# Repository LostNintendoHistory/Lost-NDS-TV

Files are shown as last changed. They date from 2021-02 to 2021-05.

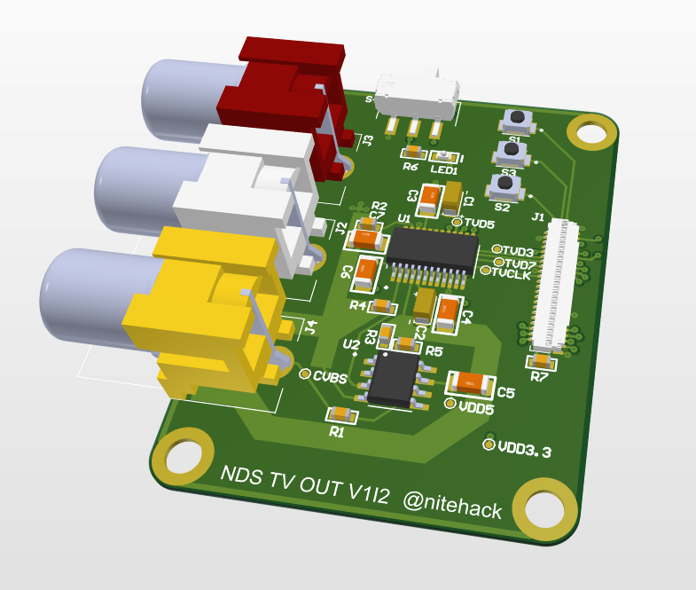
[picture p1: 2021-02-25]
pcb/media/3d_pcb_nds_tv_out_V1I2.PNG

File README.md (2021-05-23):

# Lost-NDS-TV

## Introduction

On December 2020, we discovered that the Nintendo DS Lite's SoC (System on Chip) had a hidden feature: a leftover TV(Television) composite video output signal. This project contains our hardware designs and software code to restore this hidden feature and make it usable again. More details [here](https://lostnintendohistory.github.io/DS-TV-OUT)

## Contents

 * Schematics & design & BOM
   * Can be found in this respository under /pcb
 * Production Files
   * Gerber files are available in the [releases page](https://github.com/LostNintendoHistory/Lost-NDS-TV/releases)
 * Documentation
   * Some base explaination of how the system works, how the PCB and software act altogether, etc. can be found [here](https://lostnintendohistory.github.io/DS-TV-OUT) after the Installation section
 * Tutorials
   * For a quick installation/usage tutorial, [click here](https://lostnintendohistory.github.io/DS-TV-OUT)
   * Video Tutorial coming later this month

## Video Tutorial for Installation

NDS TV OUT Installation Tutorial by radioactivepeter (https://www.youtube.com/watch?v=lBJaaE3PBwQ)

## Video analysis + installation tutorial by MachoNacho

SECRET Nintendo DS Feature Discovered! How to Enable Video-Output on the DS Lite (https://www.youtube.com/watch?v=F4n9oYBFiMI&t=1s&ab_channel=MachoNachoProductions)

## Acknowledgements 

This project wouldn't be possible without the contributions of Gericom, Nitehack and pedro-javierf.

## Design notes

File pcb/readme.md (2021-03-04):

# PCB Design Files
You have to have good soldering skills to mount the PCB with the proper equipment. A soldering station and good quality tin is recommended 

**Warning: We are not responsible for possible damage both hardware and software.
Do it under your responsibility **

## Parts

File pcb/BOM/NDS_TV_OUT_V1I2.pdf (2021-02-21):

Comment | Description | Designator | Footprint | LibRef | Quantity | Manufacturer Part Number
MAX5184BEEG+ | DAC 1-CH Current Steering 10-bit 24-Pin QSOP | U1 | SOP63P602 X175-24N | MAX5184BEEG+ | 1 | MAX5184BEEG+
MAX4414ESA+ | IC OPAMP VFB 400MHZ RRO 8SOIC | U2 | SOIC127P60 0X175-8N | MAX4414ESA+ | 1 | MAX4414ESA+
KLPX-0848A-2-Y | Conn RCA F 2 POS 4.5mm Solder RA Thru-Hole 2 Terminal 1 Port | J4 | KLPX0848A2 Y | KLPX-0848A-2-Y | 1 | KLPX-0848A-2-Y
KLPX-0848A-2-W | Conn RCA F 2 POS 4.5mm Solder RA Thru-Hole 2 Terminal 1 Port | J2 | KLPX0848A2 W | KLPX-0848A-2-W | 1 | KLPX-0848A-2-W
KLPX-0848A-2-R | Conn RCA F 2 POS 4.5mm Solder RA Thru-Hole 2 Terminal 1 Port | J3 | KLPX0848A2 R | KLPX-0848A-2-R | 1 | KLPX-0848A-2-R
JS102011SAQN | Slide Switch, JS Series, SPDT, Right Angle, SMD, 100 mA ;RoHS Compliant: Yes | S4 | SW_JS10201 1SAQN | JS102011SAQN | 1 | JS102011SAQN
DNP | | R2, R4 | R0603 | R0603 | 2
B3U-1000P | SWITCH TACTILE SPST-NO 0.05A 12V | S1, S2, S3 | SW_B3U-1000P | B3U-1000P | 3 | B3U-1000P
APTD1608LZGCK | LED GREEN CLEAR 0603 SMD | LED1 | RESC0603X5 5N | APTD1608LZGCK | 1 | APTD1608LZGCK
430R | Res, 430R, 0.1%, 0.1W, 0603, Thin | R3 | R0603 | MCWF06R4300B TL | 1 | MCWF06R4300BTL
320R | Film High Precision-High Stability Chip Resistor Thin Film 0603 320Ohm 0.5% Paper T/R | R6 | R0603 | RT0603DRE07320 RL | 1 | RT0603DRE07320RL
75R | VISHAY -CRCW060375R 0FKEA - RES, 75R, 1%, 0.1W, 0603, THICK FILM | R1 | R0603 | CRCW060375R0F KEA | 1 | CRCW060375R0FKEA
10uF | CAPACITOR, CASE A, 10UF, 10V; Product Range:KEMET -T491 Series; Capacitance:1 0µF; Capacitance Tolerance:± 10%; Voltage Rating:10V; Capacitor Case Style:1206 [3216 Metric]; Manufacturer Size Code:A; Operating Temperature Max:125°C; ;RoHS Compliant: Yes | C1, C2 | C1206T | T491A106K010AT | 2 | T491A106K010AT
4-2328724-5 | FPC Connector; 0.3mm pitch front flip FPC; 45pos | J1 | 423287245 | 4-2328724-5 | 1 | 4-2328724-5
1K | ROHM -ESR03EZPF100 1 - SMD Chip Resistor, Anti-Surge, 0603 [1608 Metric], 1 kohm, ESR Series, 150 V, Thick Film, 250 mW | R5, R7 | R0603 | ESR03EZPF1001 | 2 | ESR03EZPF1001
0.1uF | MURATA -GRM319R71H 104KA01D -COND, CERÁ MULT, X7R, 100NF, 50V, 1206 | C3, C4, C5, C6, C7 | C1206 | GRM319R71H10 4KA01D | 5 | GRM319R71H104KA01D
Ribbon Cable FPC 0,3mm pitch 45 pin | | | | | 1 | https://es.aliexpress.com/it
em/4000499971802.html?s
pm=a2g0s.9042311.0.0.415
d63c0FOSqsK (https://es.aliexpress.com/item/4000499971802.html?spm=a2g0s.9042311.0.0.415d63c0FOSqsK)

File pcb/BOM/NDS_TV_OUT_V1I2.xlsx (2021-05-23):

Comment | Description | Designator | Footprint | LibRef | Quantity | Manufacturer Part Number
MAX5184BEEG+ | DAC 1-CH Current Steering 10-bit 24-Pin QSOP | U1 | SOP63P602X175-24N | MAX5184BEEG+ | 1 | MAX5184BEEG+
MAX4414ESA+ | IC OPAMP VFB 400MHZ RRO 8SOIC | U2 | SOIC127P600X175-8N | MAX4414ESA+ | 1 | MAX4414ESA+
KLPX-0848A-2-Y | Conn RCA F 2 POS 4.5mm Solder RA Thru-Hole 2 Terminal 1 Port | J4 | KLPX0848A2Y | KLPX-0848A-2-Y | 1 | KLPX-0848A-2-Y
KLPX-0848A-2-W | Conn RCA F 2 POS 4.5mm Solder RA Thru-Hole 2 Terminal 1 Port | J2 | KLPX0848A2W | KLPX-0848A-2-W | 1 | KLPX-0848A-2-W
KLPX-0848A-2-R | Conn RCA F 2 POS 4.5mm Solder RA Thru-Hole 2 Terminal 1 Port | J3 | KLPX0848A2R | KLPX-0848A-2-R | 1 | KLPX-0848A-2-R
JS102011SAQN | Slide Switch, JS Series, SPDT, Right Angle, SMD, 100 mA ;RoHS Compliant: Yes | S4 | SW_JS102011SAQN | JS102011SAQN | 1 | JS102011SAQN
DNP |  | R2, R4 | R0603 | R0603 | 2
B3U-1000P | SWITCH TACTILE SPST-NO 0.05A 12V | S1, S2, S3 | SW_B3U-1000P | B3U-1000P | 3 | B3U-1000P
APTD1608LZGCK | LED GREEN CLEAR 0603 SMD | LED1 | RESC0603X55N | APTD1608LZGCK | 1 | APTD1608LZGCK
430R | Res, 430R, 0.1%, 0.1W, 0603, Thin Film | R3 | R0603 | MCWF06R4300BTL | 1 | MCWF06R4300BTL
320R | High Precision-High Stability Chip Resistor Thin Film 0603 320Ohm 0.5% Paper T/R | R6 | R0603 | RT0603DRE07320RL | 1 | RT0603DRE07320RL
75R | VISHAY - CRCW060375R0FKEA - RES, 75R, 1%, 0.1W, 0603, THICK FILM | R1 | R0603 | RC0603FR-0775RL | 1 | RC0603FR-0775RL
10uF | CAPACITOR, CASE A, 10UF, 10V; Product Range:KEMET - T491 Series; Capacitance:10µF; Capacitance Tolerance:± 10%; Voltage Rating:10V; Capacitor Case Style:1206 [3216 Metric]; Manufacturer Size Code:A; Operating Temperature Max:125°C; ;RoHS Compliant: Yes | C1, C2 | C1206T | T491A106K010AT | 2 | T491A106K010AT
4-2328724-5 | FPC Connector; 0.3mm pitch front flip FPC; 45pos | J1 | 423287245 | 4-2328724-5 | 1 | 4-2328724-5
1K | ROHM - ESR03EZPF1001 - SMD Chip Resistor, Anti-Surge, 0603 [1608 Metric], 1 kohm, ESR Series, 150 V, Thick Film, 250 mW | R5, R7 | R0603 | ESR03EZPF1001 | 2 | ESR03EZPF1001
0.1uF | MURATA - GRM319R71H104KA01D - COND, CERÁ MULT, X7R, 100NF, 50V, 1206 | C3, C4, C5, C6, C7 | C1206 | C1206C104K5RAC7210 | 5 | C1206C104K5RAC7210
Ribbon Cable FPC 0,3mm pitch 45 pin |  |  |  |  | 1 | https://es.aliexpress.com/item/4000499971802.html?spm=a2g0s.9042311.0.0.415d63c0FOSqsK | https://www.mouser.es/Wire-Cable/FFC-FPC-Jumper-Cables/_/N-ad930?P=1y9j0ziZ1z0wxp5

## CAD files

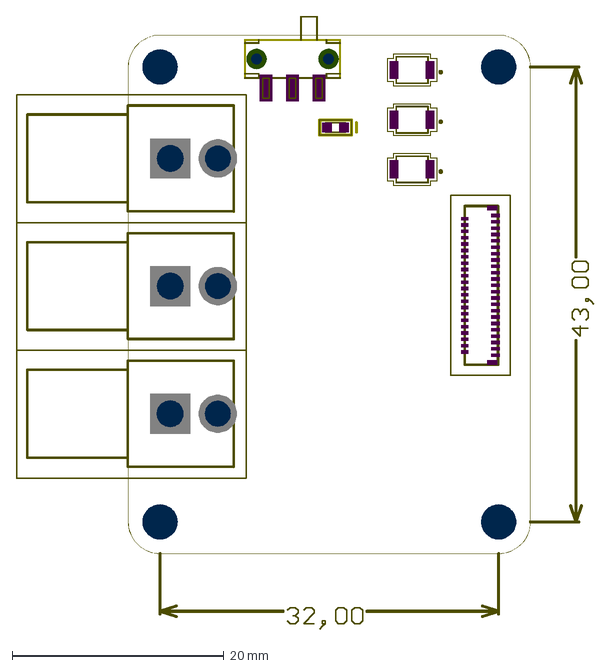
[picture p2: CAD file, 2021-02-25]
pcb/3d/mechanical nds tv out v1I2.dxf
54.6 x 57.9 mm

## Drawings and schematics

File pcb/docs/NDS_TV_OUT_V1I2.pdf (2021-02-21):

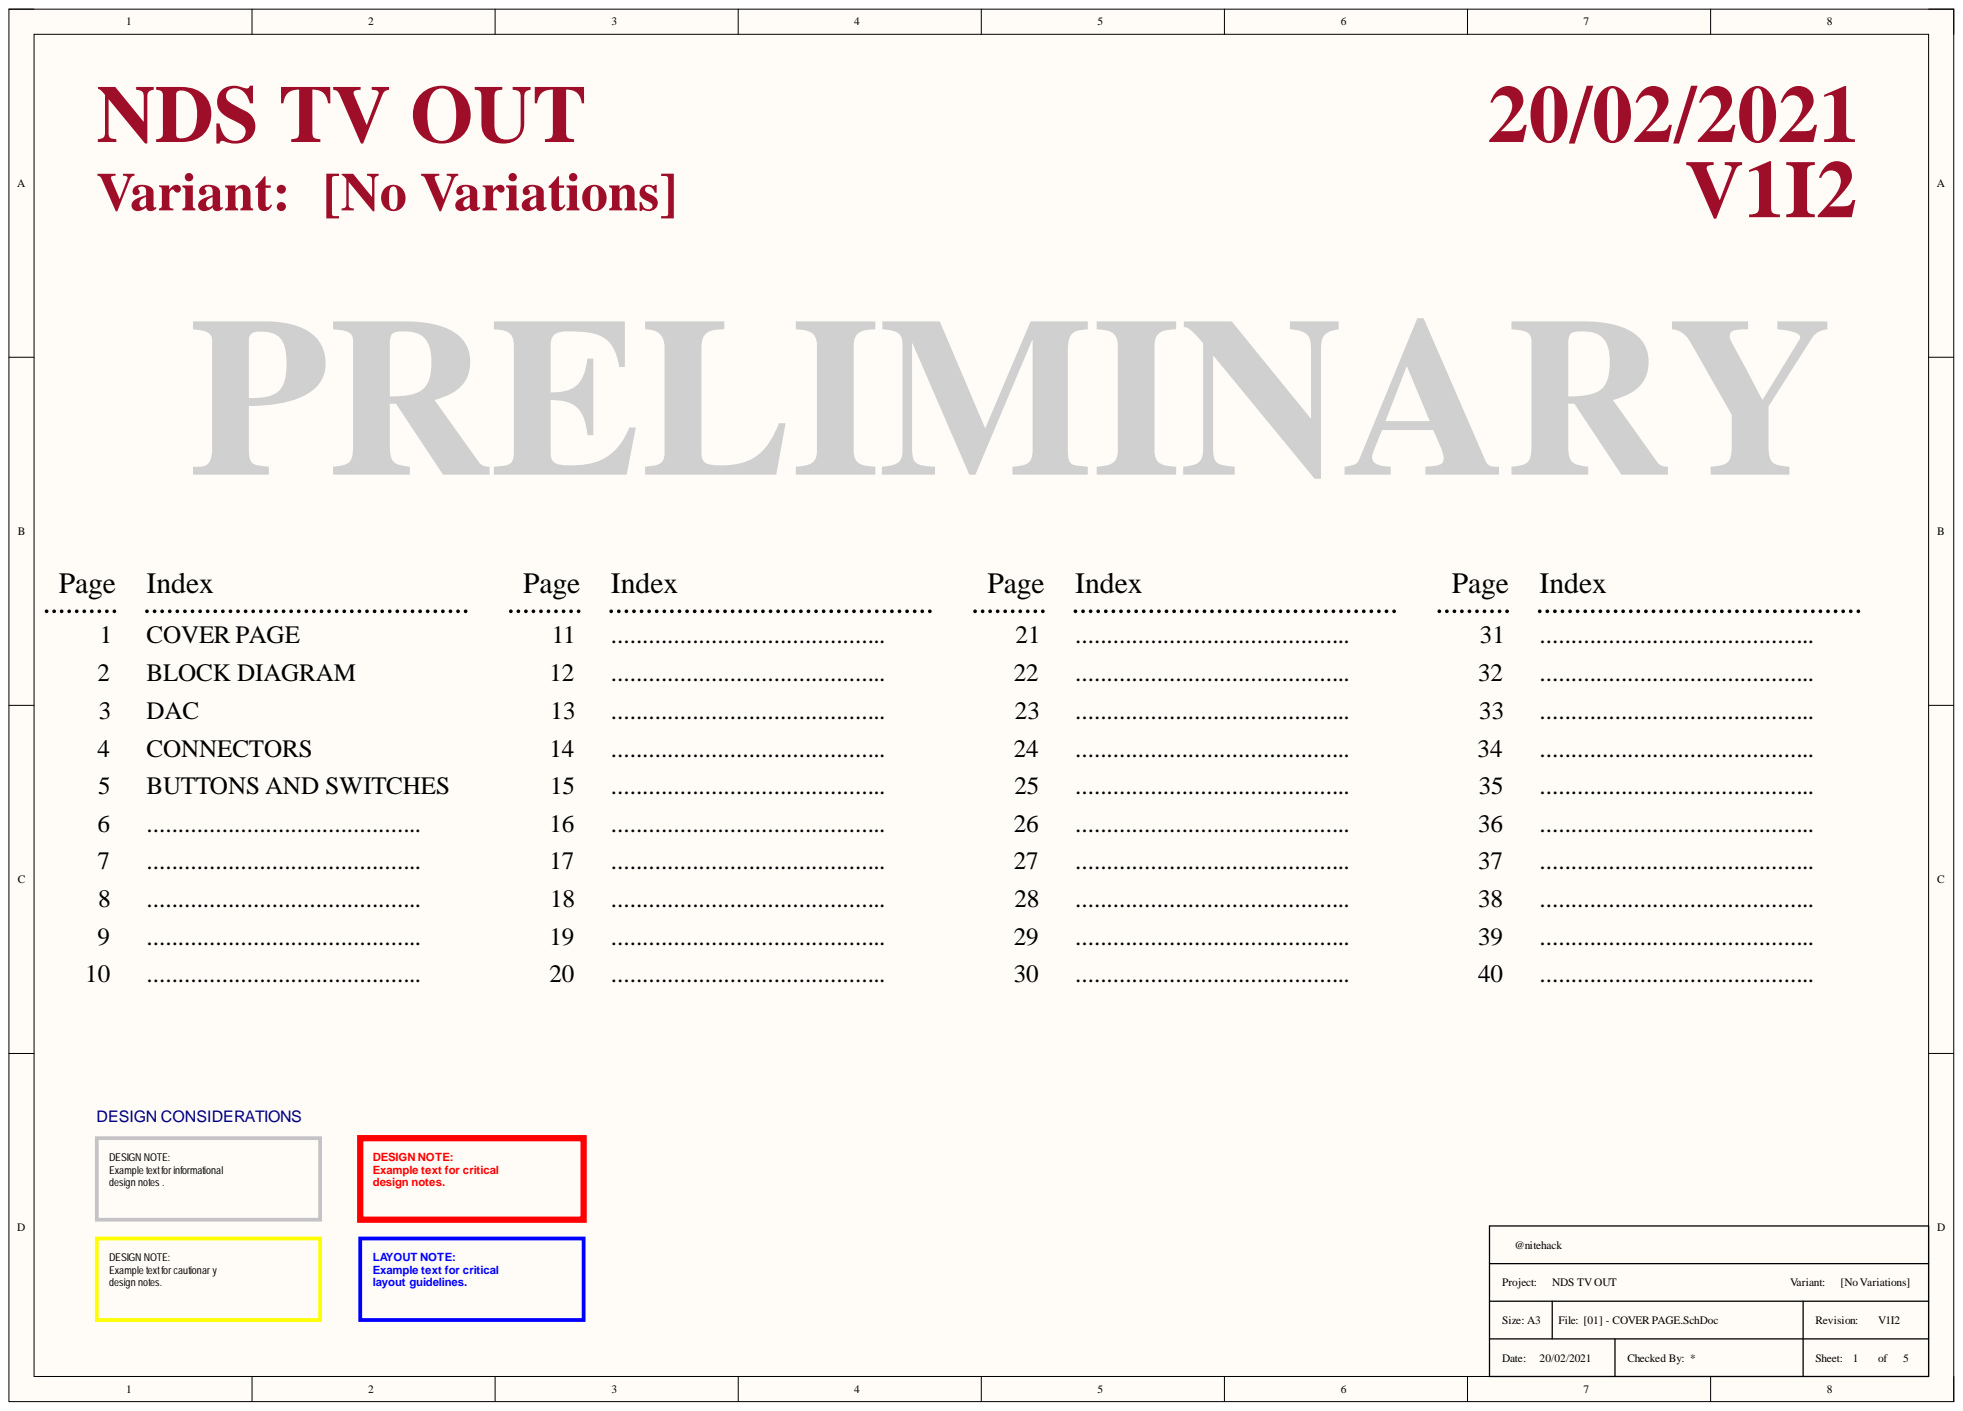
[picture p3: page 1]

DESIGN NOTE:
Example text for informational
design notes .

Example text for critical
design notes.

Example text for cautionary

LAYOUT NOTE:

Size: A3 | File: [01] - COVER PAGE.SchDoc | Revision: V1I2

Date: 20/02/2021 | Checked By: * | Sheet: 1 of 5

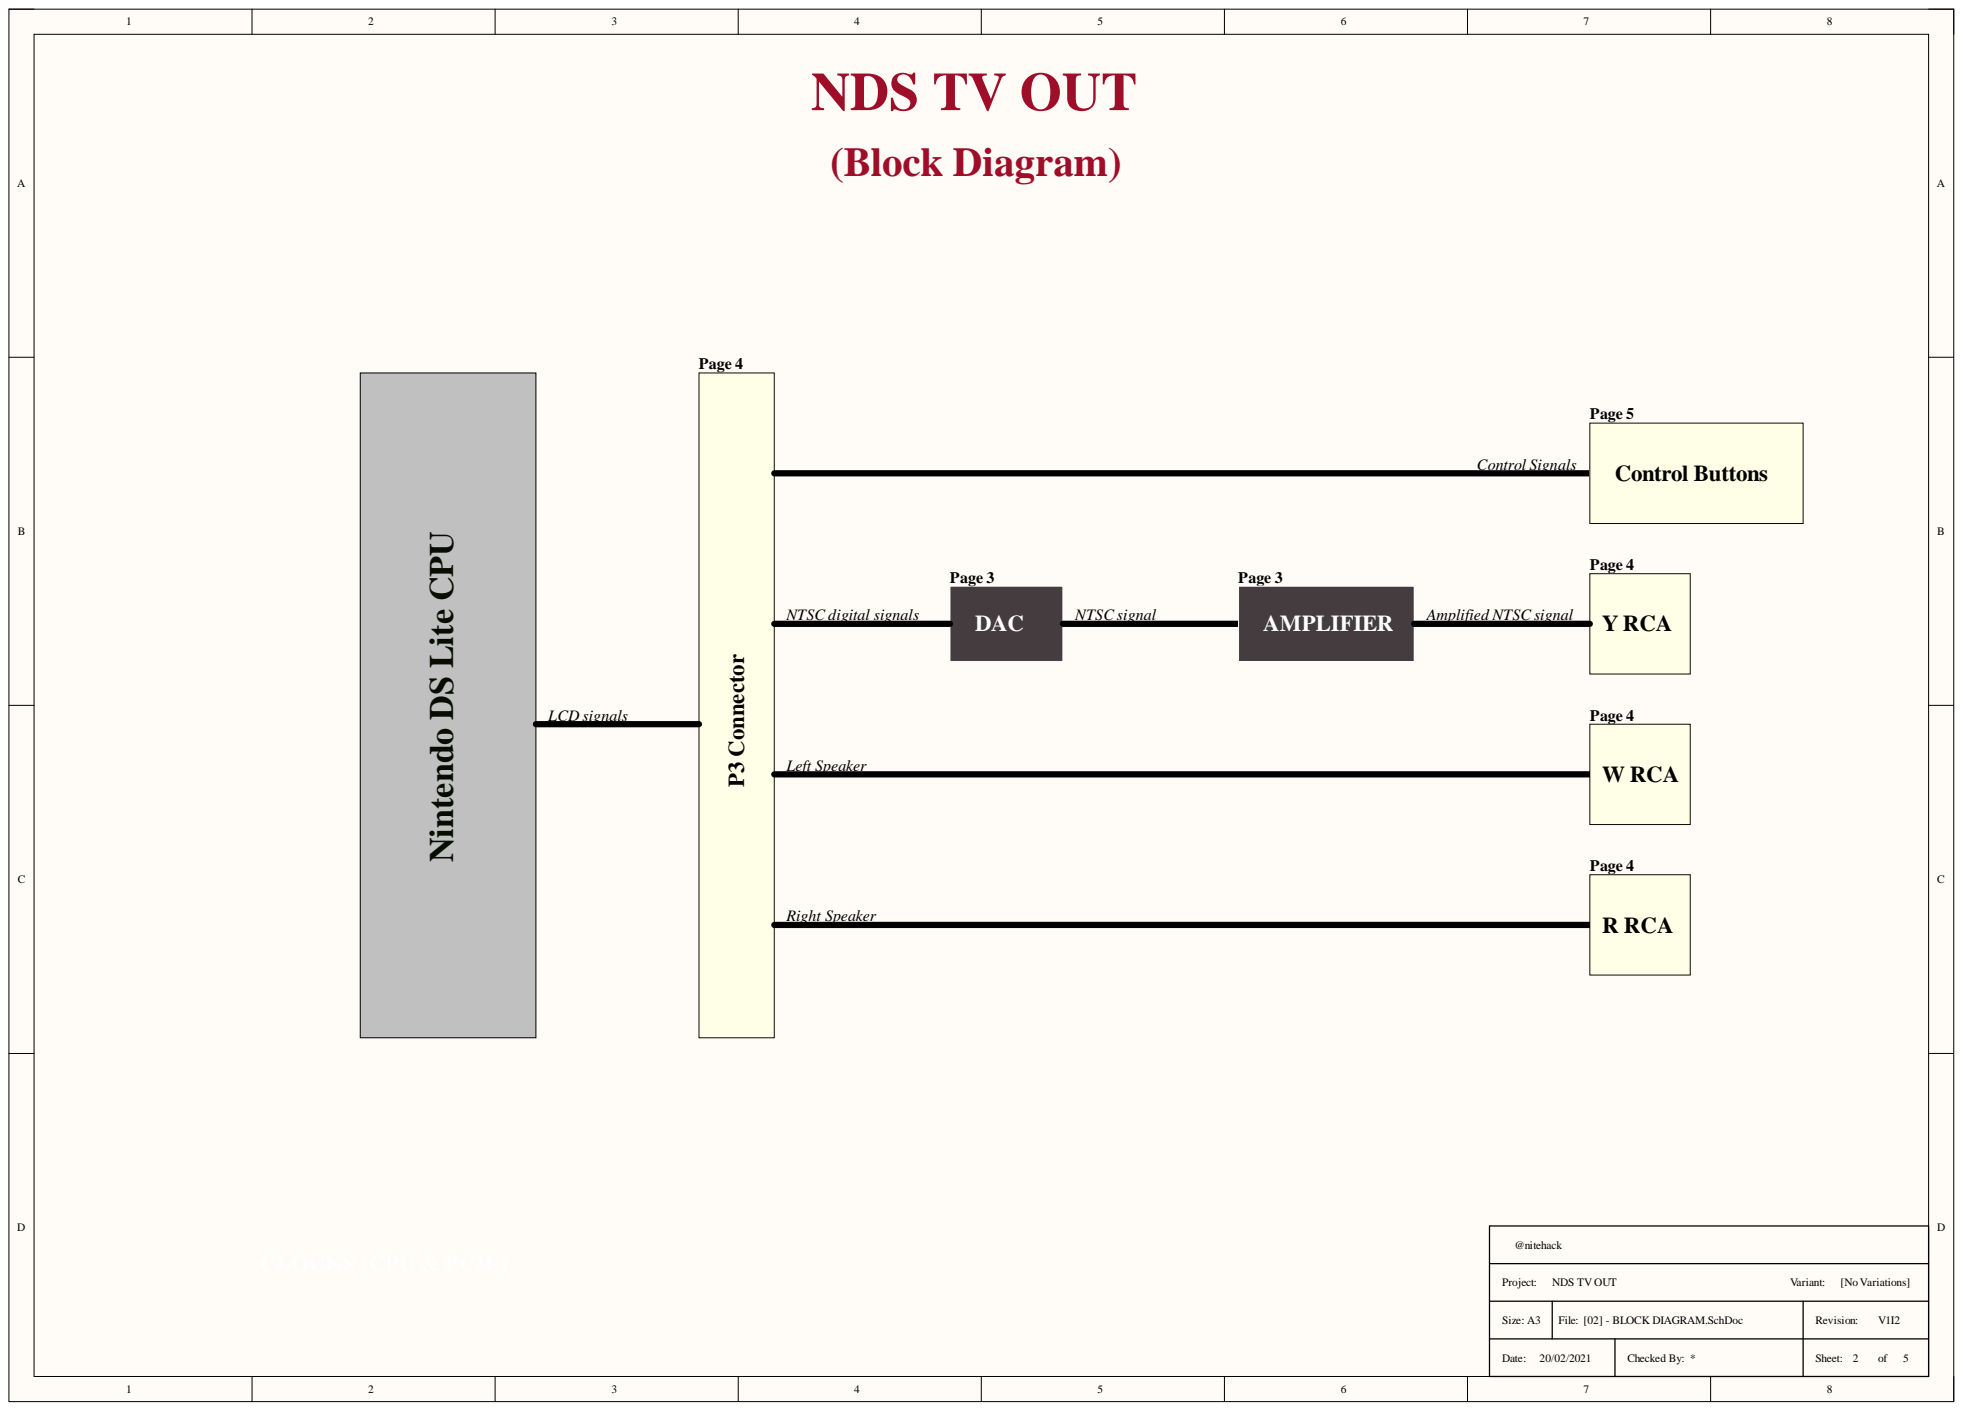
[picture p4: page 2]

Size: A3 | File: [02] - BLOCK DIAGRAM.SchDoc | Revision: V1I2

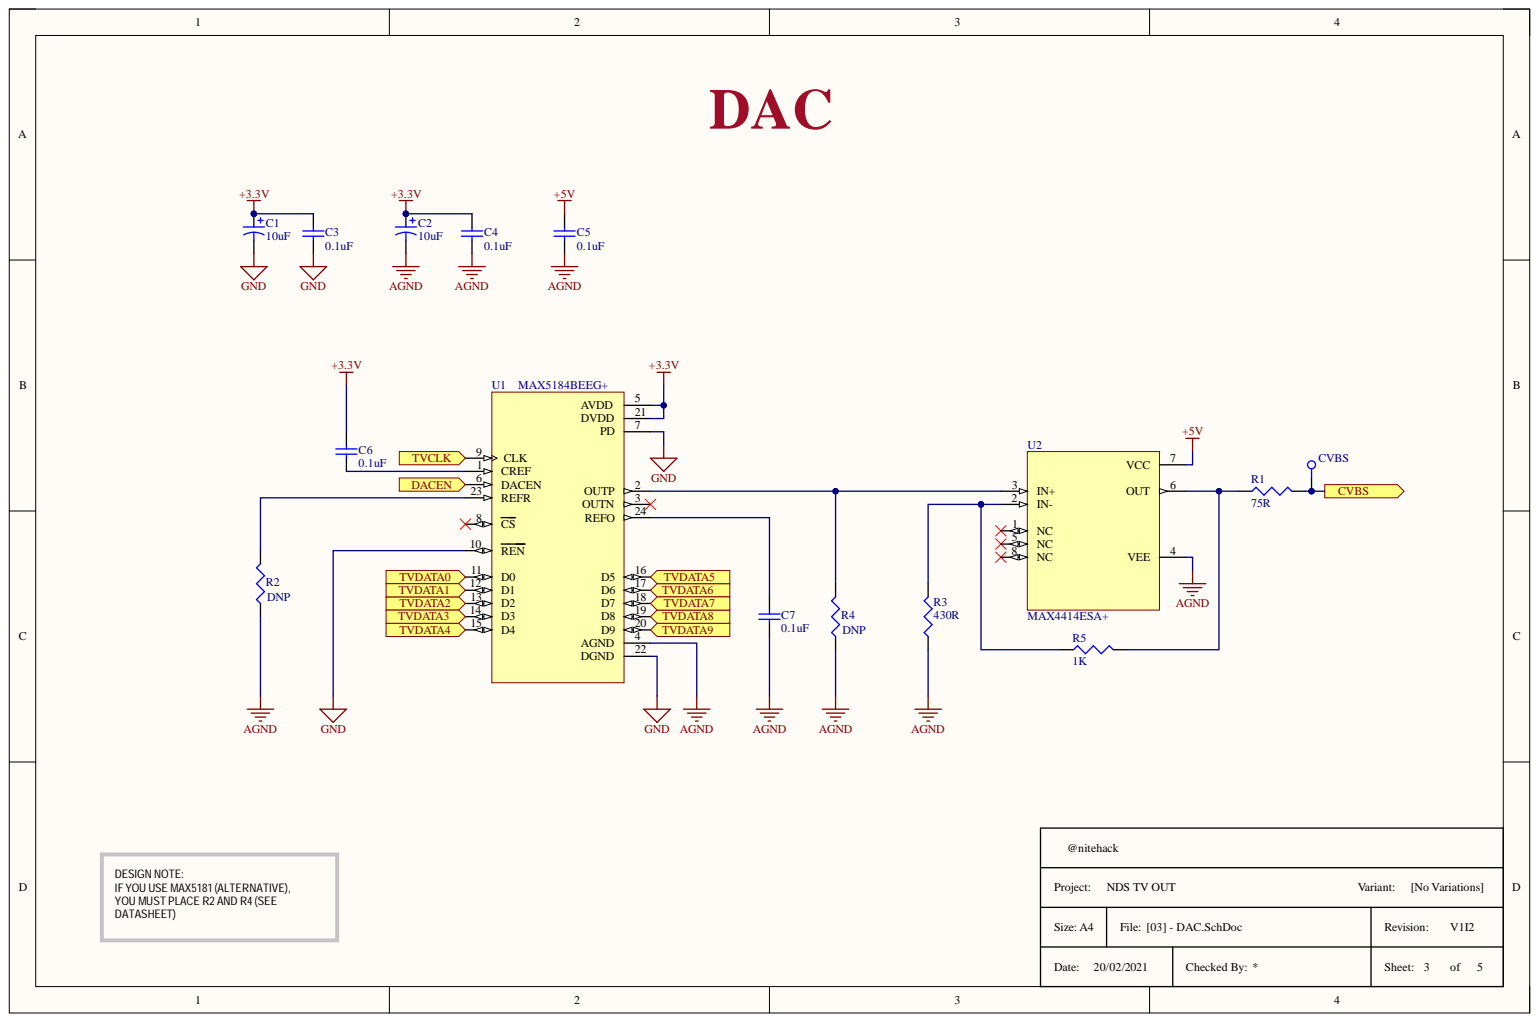
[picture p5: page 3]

TVDATA0 TVDATA1 TVDATA2 TVDATA3 TVDATA4 | D0 11

DESIGN NOTE:
IF YOU USE MAX5181 (ALTERNATIVE),
YOU MUST PLACE R2 AND R4 (SEE
DATASHEET)

Size: A4 | File: [03] - DAC.SchDoc | Revision: V1I2

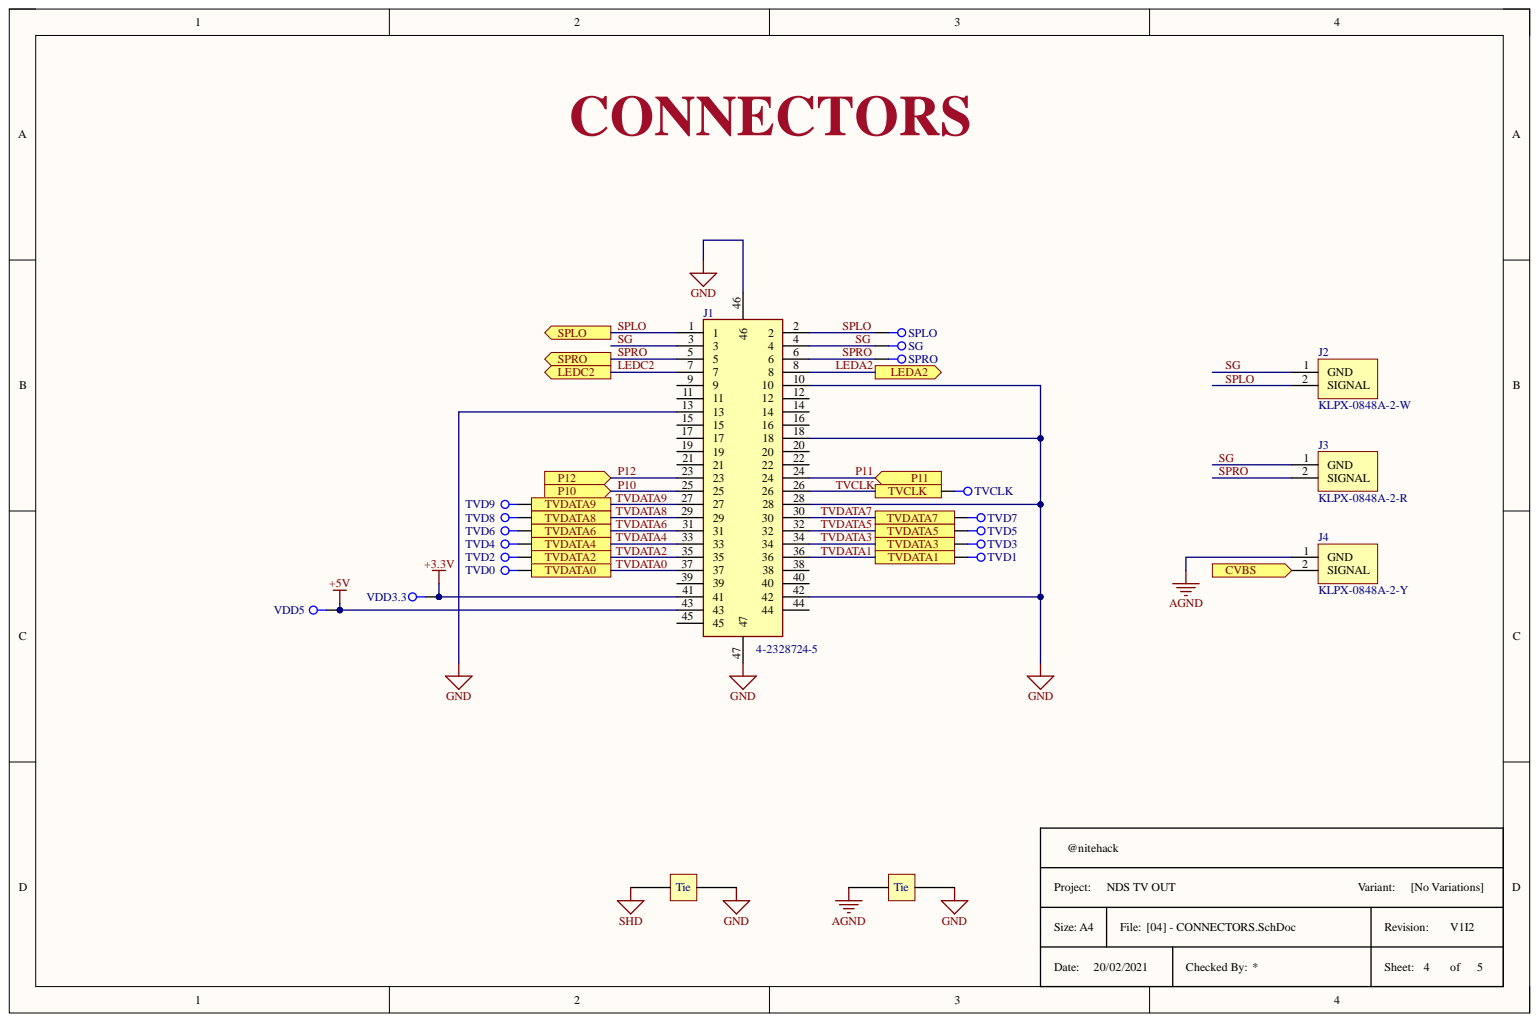
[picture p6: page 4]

Size: A4 | File: [04] - CONNECTORS.SchDoc | Revision: V1I2

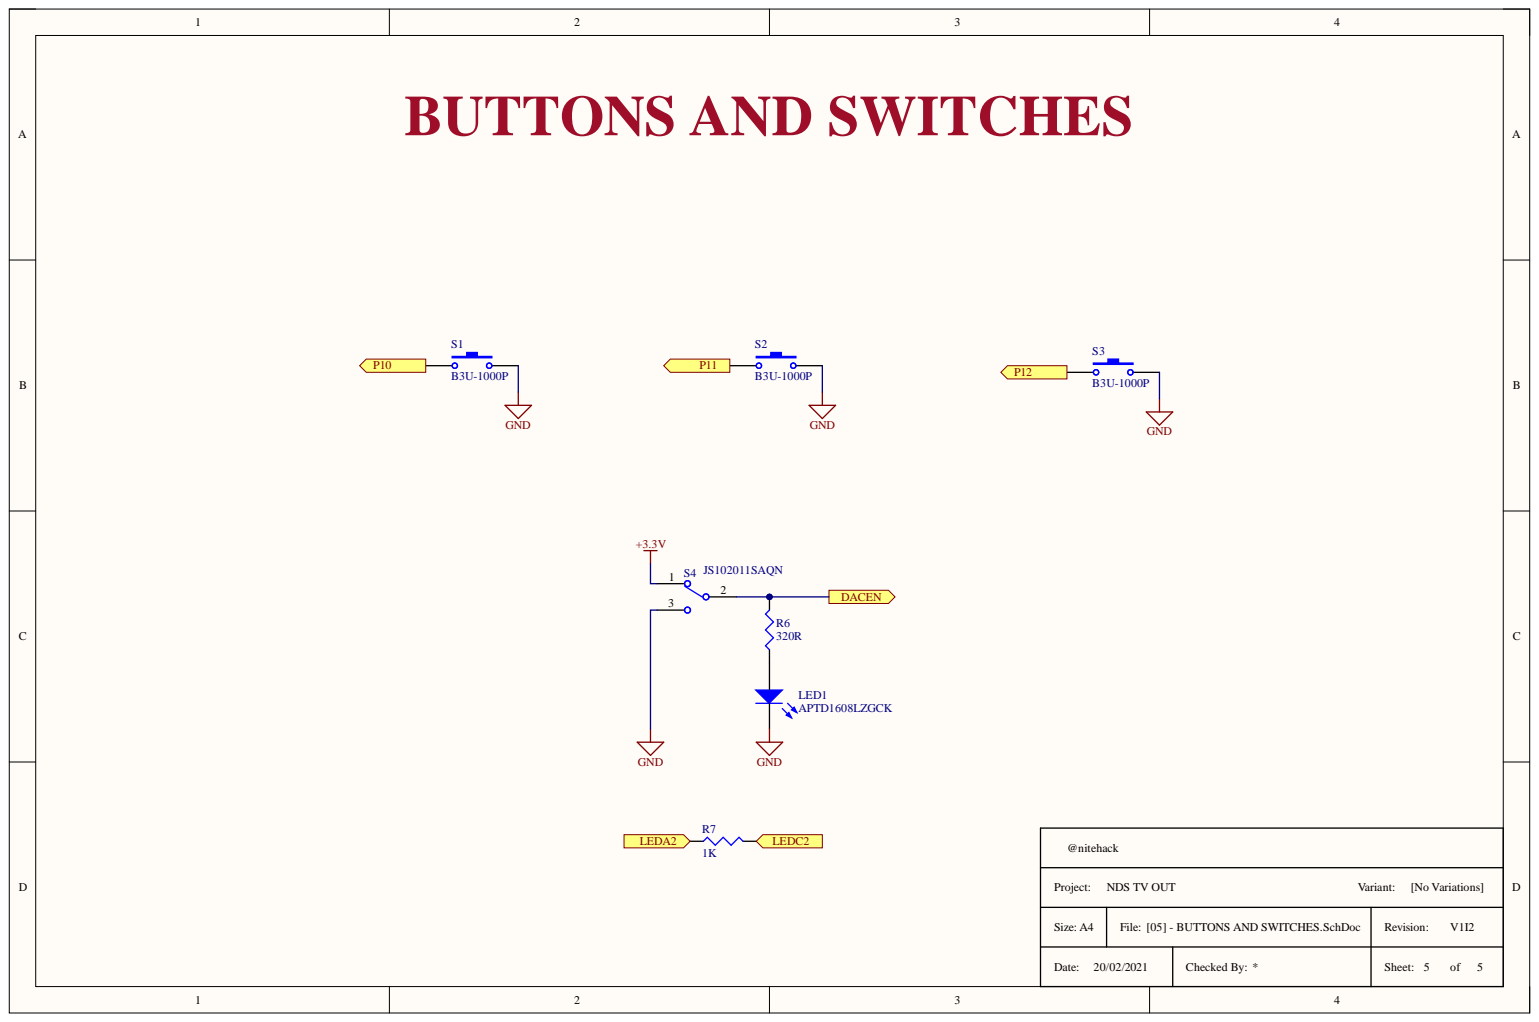
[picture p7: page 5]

Size: A4 | File: [05] - BUTTONS AND SWITCHES.SchDoc | Revision: V1I2

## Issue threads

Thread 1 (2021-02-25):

[FEATURE REQUEST] Show both screens side by side, or on top of each other, or just have seperate RCA connections for both screens? Either three would be fine, to be honest, I don't really need all three for what I am using this for.

6100m, 2021-02-25:
Love this project, but the only feature that's not here yet that I need is the one I mentioned in the title because I want this on a LCD. Touchscreen I'm not asking for just yet, but I have been researching the touchscreen signals on and off, and I even know the exact spot they are on the board. Contact me at myhacknull@gmail.com if you want to discuss the touchscreen stuff further haha.

Honestly I'd go for either three of the options, but is it even possible though?

pedro-javierf, 2021-02-25:
Unfortunately those options are not supported natively by the DS Lite SoC, so there's nothing we can do. Such a thing would require extra hardware, like a capture card hooked to each of the 2 lcd's flex.

tomrow, 2021-02-26:
Probably out of scope, but I had a theory that if the DS can cope with it, one could use a suitably fast microcontroller or something to switch screen modes every 60th of a second, and use that to generate a 480 line signal with both screens at 30 frames per second.

ItsRogueRen, 2021-05-13:
> Unfortunately those options are not supported natively by the DS Lite SoC, so there's nothing we can do. Such a thing would require extra hardware, like a capture card hooked to each of the 2 lcd's flex.

what if both flex cables went to 1 PCB that combined them into a single 512x192 video rather than two 256x192 videos? The board would have to be more expensive and maybe have something like an audrino (or similar device). Just an idea though.

ylorant, 2021-07-29:
> what if both flex cables went to 1 PCB that combined them into a single 512x192 video rather than two 256x192 videos? The board would have to be more expensive and maybe have something like an audrino (or similar device). Just an idea though.

What you are describing is basically the actual DS capture card that already exists. Uses only 1 flex though, as the console (at least the DS Tank, which the capture card is made for) sends the two screens on it (top on rising clock, bottom on falling clock iirc).

ItsRogueRen, 2021-07-31:
> > what if both flex cables went to 1 PCB that combined them into a single 512x192 video rather than two 256x192 videos? The board would have to be more expensive and maybe have something like an audrino (or similar device). Just an idea though.
>
> What you are describing is basically the actual DS capture card that already exists. Uses only 1 flex though, as the console (at least the DS Tank, which the capture card is made for) sends the two screens on it (top on rising clock, bottom on falling clock iirc).

As far as I know those are no longer being made though, Loopy hasn't made any capture cards is years.

ylorant, 2021-07-31:
> As far as I know those are no longer being made though, Loopy hasn't made any capture cards in years.

They're in stock right now.

Closed 2021-02-25.

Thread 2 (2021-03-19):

2-layer PCB version

lpla, 2021-03-19:
Hi. I am interested in ordering the PCB through a service like OSHPark or JLCPCB.

I noticed that the price is higher than other PCBs because gerbers from this project contain 4 layers. Is it really necessary to use 4 layers instead of 2?

Cheers and thank you for publishing all this content!

pedro-javierf, 2021-03-25:
Hello. Yes, 4 layers are necessary to reduce noise in the data lines. Nonetheless, it should not be more expensive than 2 layers. At least it hasn't been like that in our experience and orders so far.  Check this: https://twitter.com/Nitehack/status/1372637386035843083?s=20

lpla, 2021-03-25:
Oh, you are right. Seems like only OSHPark is more expensive using 4 layers. I will order it through JLCPCB then. Thank you!

Closed 2021-03-25.

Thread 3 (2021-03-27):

Vertical screen games

lpla, 2021-03-27:
Hi. Just wondering if there could be a way to implement rotating/flipping the output (using a switch in the PCB or something) so games like Rhythm Paradise or Brain Age could be correctly shown without physically rotating the monitor.

zurgeg, 2021-05-16:
AFAIK Brain Age doesn't use the microphone, I have my copy of it on DSiWare so maybe it's different there? Additionally, these features likely weren't implemented in the NDS-TV because it would usually have a top screen. I'm not a contributor so I wouldn't know but that's just my thoughts.

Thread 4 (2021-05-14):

Digital to digital output?

Numbski, 2021-05-14:
Reading over your description here:

https://lostnintendohistory.github.io/DS-TV-OUT.html

"The final, production-ready board contains a DAC (Digital to Analogue Converter) which turns the 10 bits digital signal at 16.7 MHz provided by the DS Lite into a proper analogue signal. This signal then goes through an operational amplifier and it’s ready to be delivered to your nearest TV trough composite video."

If I am reading this correctly, wouldn't it be possible to output this via DVI or DisplayPort?  I may be misunderstanding, and that may require RGB encoded data for conversion, whereas this bitstream may just be the single CVBS - but somewhere in the back of my brain, I would swear either DVI or DisplayPort can handle that.  I am going to go do some digging - but that would obviously require fiddling with the bitstream on the fly to make it work, but every little bit of help we can give the signal, the better.

Numbski, 2021-05-14:
Coincidentally, TDMS (DVI, HDMI) can also be 10-bit.  Who knows what your 10 bits are versus TDMS 10-bit, but that's a thing.

dogtopus, 2021-05-15:
Looks like it's possible, but it would probably be no different than a composite to DVI converter, minus the ADC. Honestly it sounds like too much work for subpar result (comparing to regular RGB to DVI/HDMI aka the expensive converter).

Numbski, 2021-05-15:
Maybe, maybe not.  I'm headed to bed, cuz it's late where I am, but the question is what we have in data coming across that ribbon cable.  Again, if I'm reading it right, it says it is cvbs - but 10-bit encoded, which would make that a very unusual bitstream.  That ribbon cable was assumedly supplying digital video to the top screen before, so I would assume somewhere in that tangle of data that rgb data is in there somewhere.  Still a whole lot of assumptions on my part.  I'd like to spend some time getting into the nuts and bolts of what is happening here.  Otherwise I feel silly shooting from the hip.

I do contend that it would be a better result (cvbs digital to digital) than going analog.  Sure, not by a huge margin, but still an improvement.

dogtopus, 2021-05-15:
> Maybe, maybe not. I'm headed to bed, cuz it's late where I am, but the question is what we have in data coming across that ribbon cable. Again, if I'm reading it right, it says it is cvbs - but 10-bit encoded, which would make that a very unusual bitstream. That ribbon cable was assumedly supplying digital video to the top screen before, so I would assume somewhere in that tangle of data that rgb data is in there somewhere. Still a whole lot of assumptions on my part. I'd like to spend some time getting into the nuts and bolts of what is happening here. Otherwise I feel silly shooting from the hip.
>
> I do contend that it would be a better result (cvbs digital to digital) than going analog. Sure, not by a huge margin, but still an improvement.

If I understand correctly the DS (or at least DS Lite) uses a [6-bit RGB interface](https://jrainimo.com/build/category/projects/splice-of-pi/) by default for the screens. This project uses patched firmware to trick the display engine into outputting composite video signal (without the "PHY", which this project implements) instead. So if you are looking for RGB output this might not be appropriate. Also one of the goal for this project is to avoid FPGA, but it will probably be tricky to do composite (digital or not) to DVI/HDMI conversion without one. Off the shelf converters might be an option but those are likely to be one-chip solutions with built-in ADC and so because they want to be cheap.

Again I could be wrong. So devs feel free to correct me if I am.

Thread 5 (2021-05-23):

Gerber Files missing drill file?

rolography, 2021-05-23:
Hello,

Please forgive me as I'm new to all of this. I'm not worried about the soldering but I want to get the PCB made and the drill file appears to be missing from the archive. Is a drill file available? Should I proceed without it?

Thank you in advance!

nitehack, 2021-05-23:
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

Hi!
Check NC Drill folder

rolography, 2021-05-23:
Will do! Thank you!

rolography, 2021-05-23:
Please forgive my ignorance. I went through the RAR file and the other project files and could not find the drill folder. Any suggestions on where to look?

Dunnymeister, 2021-05-24:
In the latest .rar file from the [releases page](https://github.com/LostNintendoHistory/Lost-NDS-TV/releases/tag/v1.2) root are two folders: https://puu.sh/HJbuh/b2b99c0a67.png

rolography, 2021-05-24:
Thank you! I found it.

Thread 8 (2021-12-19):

Top Screen With yellow color, after New firmware was installed!

fredito1212, 2021-12-19:
Hello, as the title describe, my only question is if this is okay, or maybe i did something wrong applying the patch or on another step, i tried the firmware on No$GBA but, with bios from internet, and it works well, but with the dumped bios from the console, it shows an error message, thats all the strange things i noticed, Thank you for any respones.! Great job with the project i'm amazed with the results!

pedro-javierf, 2021-12-19:
Did you install "flashme v8a noauto", dumped it, and applied the patch to it? If you are just dumping and patching directly to the retail firmware, it won't work!

fredito1212, 2021-12-19:
> Did you install "flashme v8a noauto", dumped it, and applied the patch to it? If you are just dumping and patching directly to the retail firmware, it won't work!

Thank you for replying, yes i actually install flashme as first, after dumped, patched with IPS and reinstalled with the firmware patched, but i cant find any further information on video o manual about wich is the finally result.

I can add, all the info i read online, even on youtube videos, everyone use only the lower part of the nintendo ds to do the modification and use the TV OUT, i did the proccess on a perfect state DS, so only my top screen is presenting the yellowing tint i mentioned before, im waiting for the needed pieces to try the video out, as a final comment, maybe because i use both screens with the new firmware, make the top screen presents this yellowing layer, i'll add a picture to show what i'm trying to describe. I got a backup of the "original" firmware so maybe i can restore it as default whitout any modifications. Thank you for all, i appreciate the time.

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

pedro-javierf, 2021-12-19:
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

Oh, yes. This is the normal behaviour when the Custom Firmware is used. The top screen starts receiving the signal as formated for TV, which is slightly different than what the LCD expects. So you can still see the shapes on the screen but the colours and the overall signal is not proper. When it is yellow like that, it means the signal should actually be being sent to the NDS-TV-OUT pcb board. There is no "solution" for this because this is the expected behavior

SonGoku-2000, 2023-11-12:
One possible "solution" could be to add an option to enable and disable the tv output.
But I don't know how hard it is to do that.

Kiriox94, 2023-11-25:
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

Hello, I have the same problem. But this post is from a while ago. In the meantime, have you found a solution?

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

Hello, I have the same problem. But this post is from a while ago. In the meantime, have you found a solution?

Frahack, 2024-10-29:
Having the same problem here, i think it is normal, but if anyone can find a solution it will be appreciated

nitehack, 2024-11-23:
> Having the same problem here, i think it is normal, but if anyone can find a solution it will be appreciated

This is normal behavior. Please note that the composite video signal, which then go to the DAC to connect to the TV, are being transmitted through the same bus that sends color information to the LCD. This is why the screen appears this way. If you install the original firmware, you will see that this "issue" disappears

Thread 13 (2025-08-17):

Missing firmware patch file (ndstvout-patch.ips)

HrabiaLipton, 2025-08-17:
Hello,

I'm trying to follow the DS Lite TV-out mod instructions. The documentation and external guides (such as Facelesstech) mention a firmware patch file located at fwpatch/ndstvout-patch.ips.

However, the current repository (and its history) does not include this file, and it is also missing from the v1.2 release package. Without this `.ips` file, it’s not possible to patch the DS Lite firmware.

Could you please restore the file, or provide a link where it can be downloaded?

Thank you very much for your help, and for keeping this project alive!

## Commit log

2021-02-21 NDS TV OUT V1I2
    [NDS_TV_OUT.SchDoc, NDS_TV_OUT_PCB_V1I2.PcbDoc, NDS_TV_OUT_V1I2.PrjPcb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]
2021-02-25 Added file for pick and place
    [Pick Place for NDS_TV_OUT_PCB_V1I2.csv]
2021-02-25 3d body of nds tv out pcb
2021-02-25 Added DXF of nds tv out pcb v1I2
    [mechanical nds tv out v1I2.dxf]
2022-08-17 Upload PCB project in ASCII exported format
    For importing in other EDA tools
